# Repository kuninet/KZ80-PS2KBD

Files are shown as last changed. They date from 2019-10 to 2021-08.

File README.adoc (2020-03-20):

= KZ80マイコン用 MSX互換 PS/2キーボードアダプタ = 

== 概要 ==
* PS/2キーボードのシリアル信号をATMega328P AVRマイコンでMSX互換のPPI(8255)へつなげるボードです。
** PS/2キーボードのシリアル信号をATmega328Pの外部割り込み機能で受信
** AVRマイコン内部でMSXがおこなっているPPI(8255) Cポートのスキャン信号をもとにポート変化割り込み変化割り込みが届いた場合に、PPI(8255)Bポートへスキャンコードを出力します。

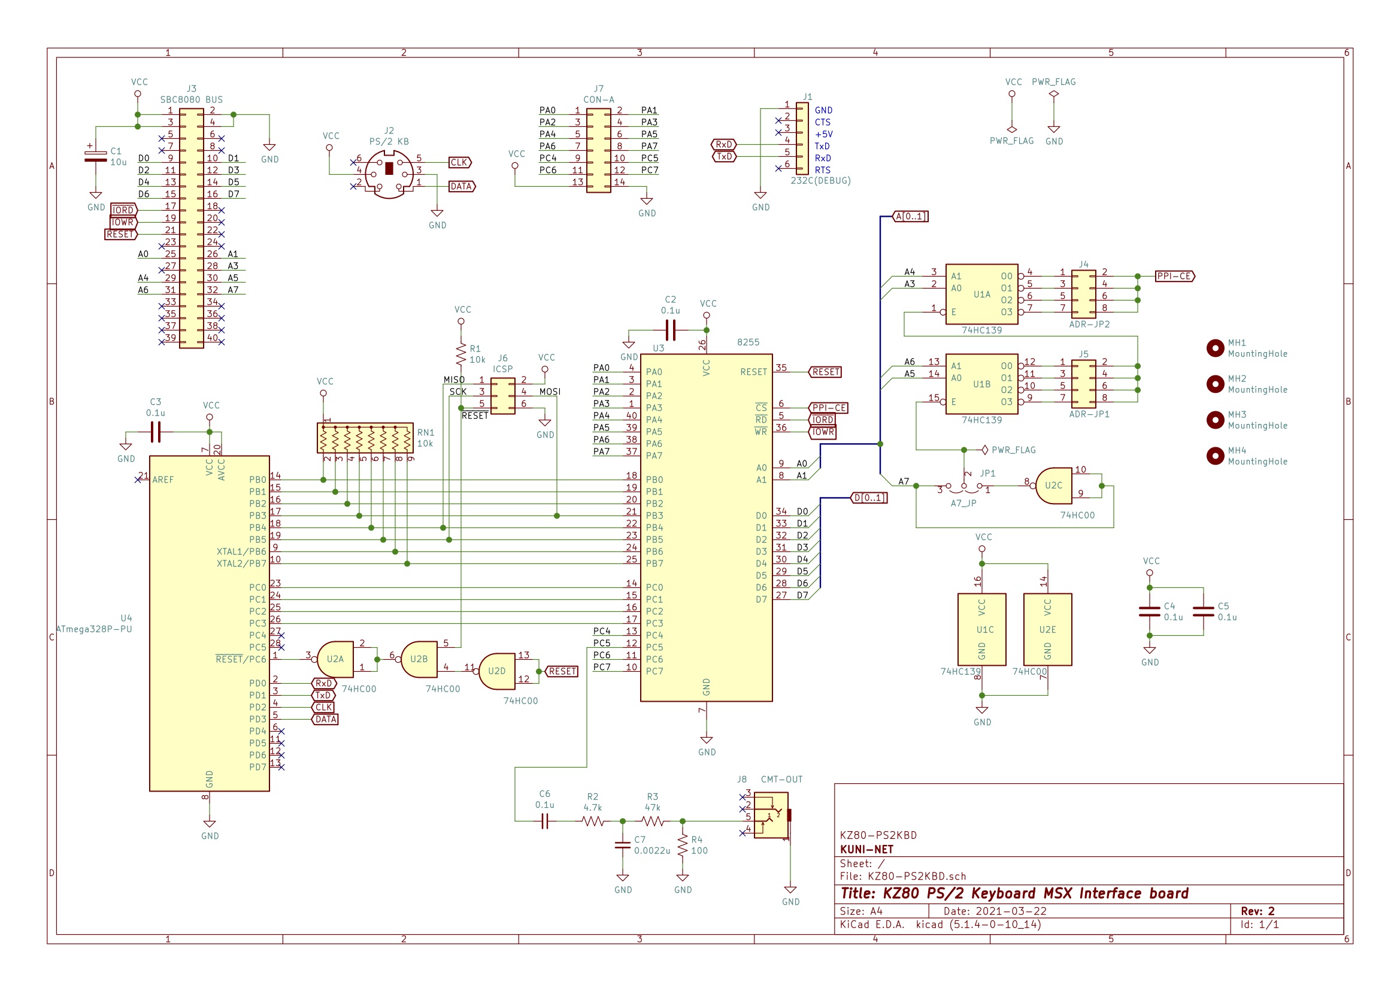
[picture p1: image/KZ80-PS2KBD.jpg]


== 注意 ==
* **REV1基板には74HC00の電源が逆接続という重大なバグがあります。REV2をお待ち下さい。**
** 74HC00の電源ピンが逆なので、ICソケット2段などで工夫して配線修正してください。 

== ライセンスについて
* 私が作成した回路、プログラム(改修部分)等についてはMITライセンスで公開します。
* オリジナルとなったプログラムコード部分は以下のMSX Hobby氏に帰属します。
* PS/2キーボードのフットプリントはAgilack氏の成果を使わせていただきました。ライセンスはCC-by-SAです。

=== 参考・使用させていただいた情報
* mini DINパーツのフットプリント
** https://github.com/Agilack/contrib-kicad_parts
* ArduinoMEGAでPS/2キーボードをMSXへ(MSX Hobby)
** http://msx.gouget.com.br/2014/06/24/ps2-keyboard-to-msx-with-arduino/
* Custom KiCad Libraries
** https://github.com/4x1md/kicad_libraries

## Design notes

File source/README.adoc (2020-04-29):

= KZ80マイコン MSX互換 PS/2キーボードアダプタ用 ATmega328Pプログラム =

== 概要 ==
* KZ80マイコン MSX互換 PS/2キーボードアダプタ用 のATmega328Pのためのプログラムです。
** Arduinoのスケッチの形式となっています。
** ATmega328Pは内蔵CR発振器(8MHz)で稼働させます。
** 本ボードは、PS/2キーボードのデータをATmega328Pマイコンでうけとって、MSXのキースキャン(8255)に対してキースキャンの信号線を出力する仕組みとなっています。(元になった仕組みについては、参考URLを参照ください)

== ATmega328への書き込み手順 ==
. ブートローダーの書き込み
+
* まず、ATmega328PへArduinoIDEを使ってブートローダーを書き込んでください。
** 参考URL
*** https://kuninet.org/2020/03/22/kz80%e3%83%9e%e3%82%a4%e3%82%b3%e3%83%b3%e3%82%92-%e5%81%bdmsx1%e3%81%b8%e3%80%9cps-2%e3%82%ad%e3%83%bc%e3%83%9c%e3%83%bc%e3%83%89msx%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
**** KZ80マイコンを 偽MSX1へ〜PS/2キーボードMSXアダプタ(3)
*** http://teppodone.hatenadiary.jp/entry/ArduinoIDE1.8.5_8MHz_internalClock_ATmega328P
**** 「【ArduinoIDE1.8.x】ATmega328PでArduinoを作る(内蔵8MHz使用)」自作武器を作ろうず
* KZ80マイコン MSX互換 PS/2キーボードアダプタにはICSP用端子(6pin)を用意していますので、ArduinoIDEからUSBASP等のプログラマで書き込み可能です。(AtduinoUNOのArduinoISPスケッチなどでも可能だと思われます)
. PS/2キーボードサポートのスケッチを書き込み
+
* ブートローダーのかきこみが終了したら、PS2_KZ80フォルダに入っている `PS2_KZ80.ino` をArduinoIDEをつかってATmega328Pへ書き込んでください。
** スケッチの書き込みも書き込みもブートローダー同様 USBASPなどをICSP端子へつないで実施します。
** スケッチ書き込みはArduinoボードで書き込む際の[→]ボタンアイコンではなく、プルダウンメニューの「スケッチ」>「書き込み装置を使って書き込む」を使用してください。

== 参考 ==
* 本プログラムは以下の以下のMSX Hobby氏のプログラムを使用し、KZ80-PS2KBD用にカスタマイズさせていただきました。
** ArduinoMEGAでPS/2キーボードをMSXへ(MSX Hobby)
*** http://msx.gouget.com.br/2014/06/24/ps2-keyboard-to-msx-with-arduino/

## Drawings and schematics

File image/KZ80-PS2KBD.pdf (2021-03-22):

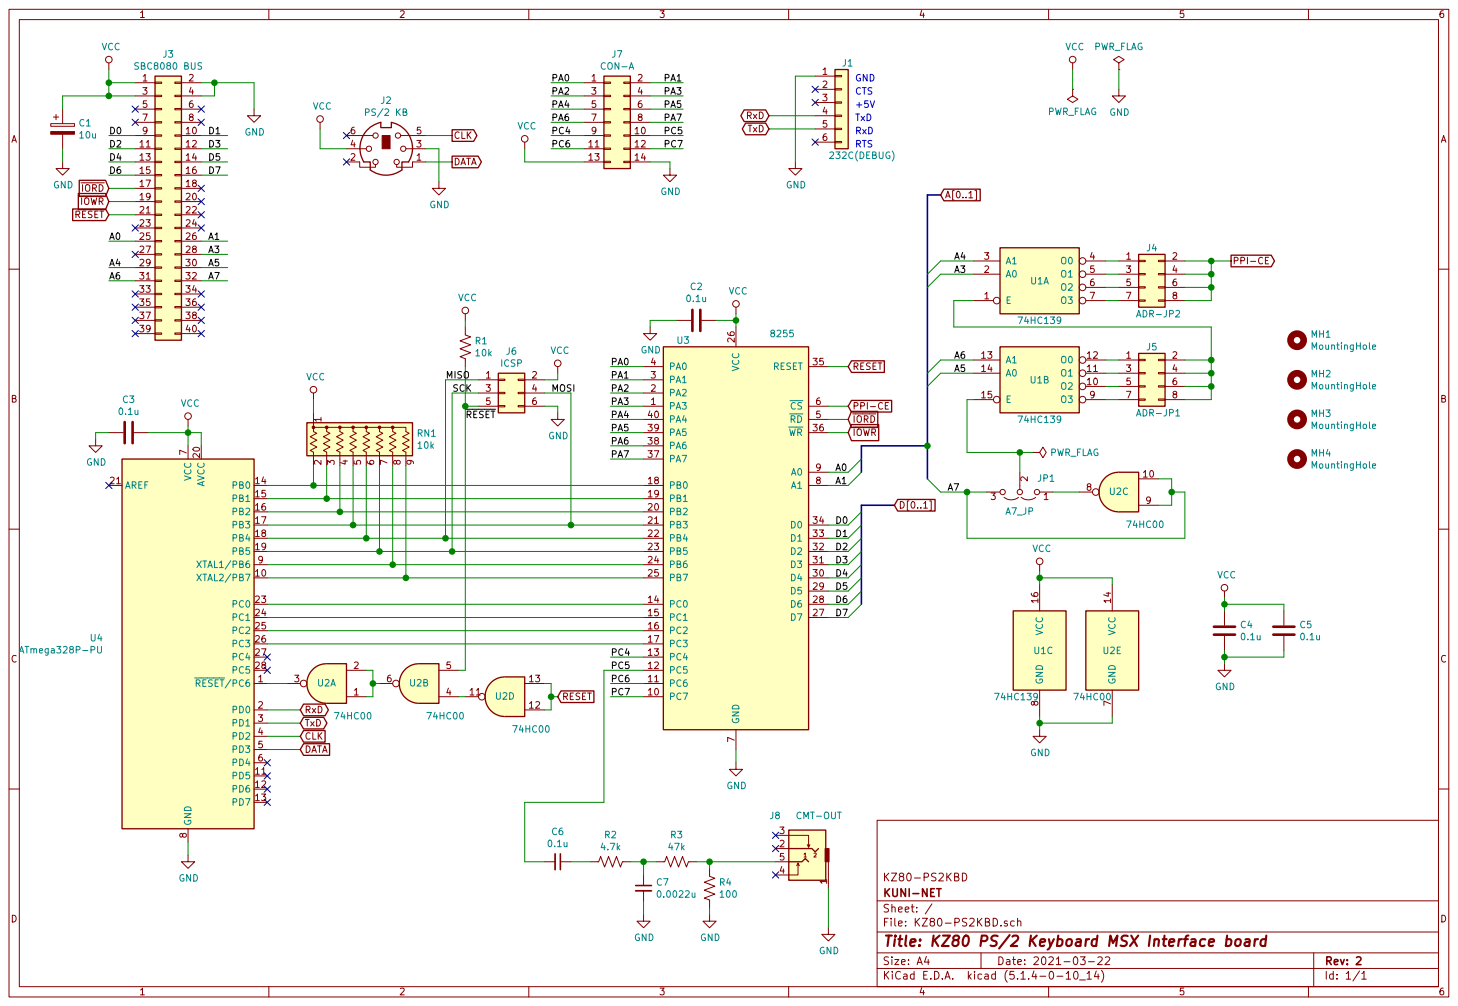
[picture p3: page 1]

SCK | 3 | 4

File: KZ80-PS2KBD.sch Sheet: / KUNI-NET KZ80-PS2KBD

Id: 1/1 Title: KZ80 PS/2 Keyboard MSX Interface board

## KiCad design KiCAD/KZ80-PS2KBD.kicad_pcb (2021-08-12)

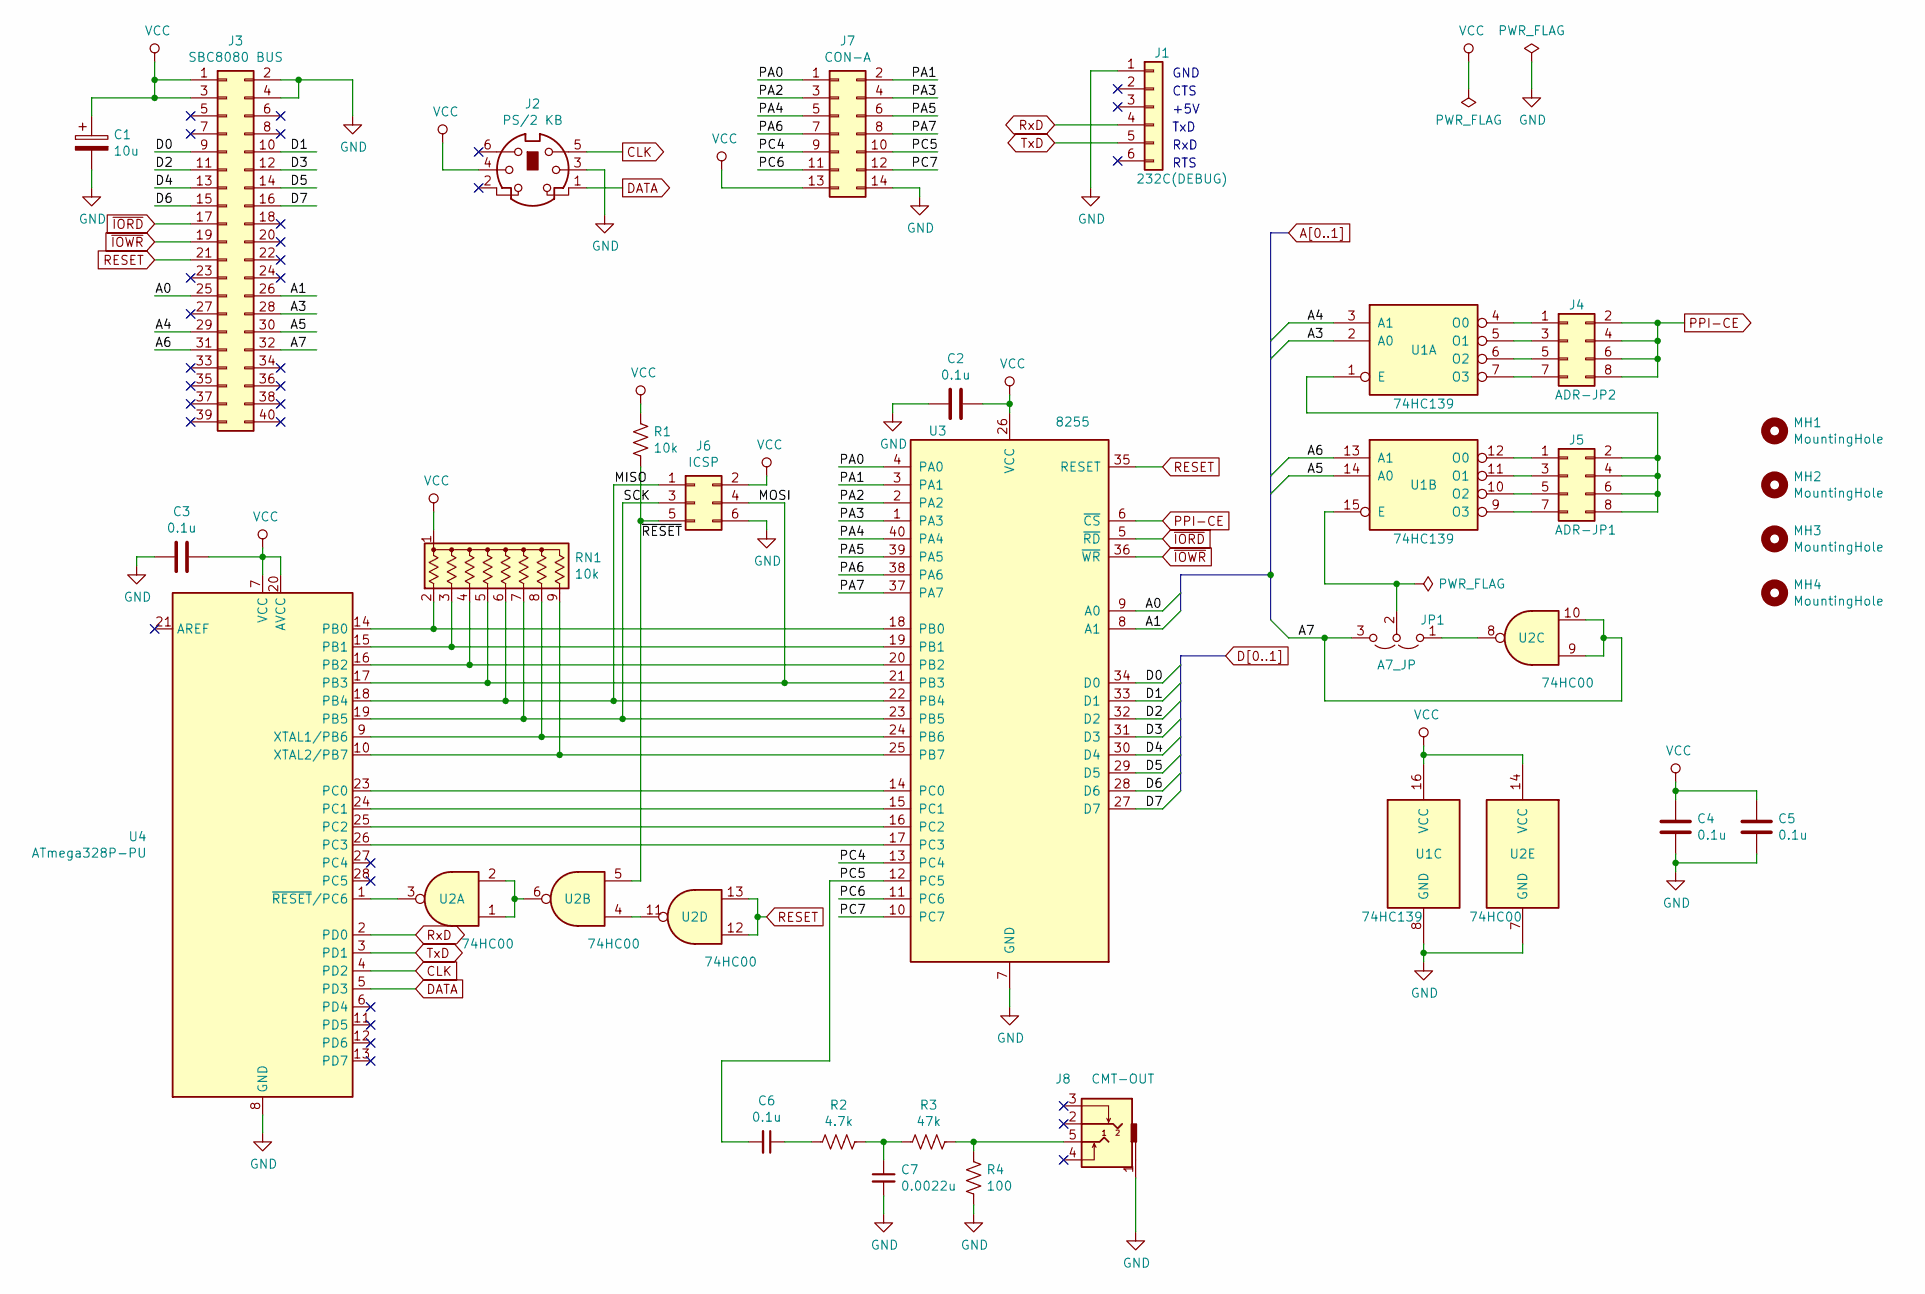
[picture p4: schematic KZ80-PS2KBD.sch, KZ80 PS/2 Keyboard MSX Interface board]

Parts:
C1: 10u; CP_Radial_D5.0mm_P2.50mm
C2, C3, C4, C5, C6: 0.1u; C_Disc_D3.0mm_W1.6mm_P2.50mm
C7: 0.0022u; C_Disc_D3.0mm_W1.6mm_P2.50mm
J1: 232C(DEBUG); PinHeader_1x06_P2.54mm_Horizontal
J2: PS/2 KB; din6-schurter-4850261
J3: SBC8080 BUS; PinHeader_2x20_P2.54mm_Horizontal
J4: ADR-JP2; PinHeader_2x04_P2.54mm_Vertical
J5: ADR-JP1; PinHeader_2x04_P2.54mm_Vertical
J6: ICSP; PinHeader_2x03_P2.54mm_Vertical
J7: CON-A; PinHeader_2x07_P2.54mm_Vertical
J8: CMT-OUT; AJ-1780
JP1: A7_JP; PinHeader_1x03_P2.54mm_Vertical
MH1, MH2, MH3, MH4: MountingHole; MountingHole_3.2mm_M3
R1: 10k; R_Axial_DIN0207_L6.3mm_D2.5mm_P10.16mm_Horizontal
R2: 4.7k; R_Axial_DIN0207_L6.3mm_D2.5mm_P10.16mm_Horizontal
R3: 47k; R_Axial_DIN0207_L6.3mm_D2.5mm_P10.16mm_Horizontal
R4: 100; R_Axial_DIN0207_L6.3mm_D2.5mm_P10.16mm_Horizontal
RN1: 10k; R_Array_SIP9
U1: 74HC139; DIP-16_W7.62mm_Socket
U2: 74HC00; DIP-14_W7.62mm_Socket
U3: 8255; DIP-40_W15.24mm_Socket
U4: ATmega328P-PU; DIP-28_W7.62mm_Socket

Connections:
/A3: J3.28, U1.2 (A0)
/A4: J3.29, U1.3 (A1)
/A5: J3.30, U1.14 (A0)
/A6: J3.31, U1.13 (A1)
/A7: J3.32, JP1.3 (B), U2.9, U2.10
/D2: J3.11, U3.32 (D2)
/D3: J3.12, U3.31 (D3)
/D4: J3.13, U3.30 (D4)
/D5: J3.14, U3.29 (D5)
/D6: J3.15, U3.28 (D6)
/D7: J3.16, U3.27 (D7)
/MISO: J6.1, RN1.6 (R5), U3.22 (PB4), U4.18 (PB4)
/MOSI: J6.4, RN1.5 (R4), U3.21 (PB3), U4.17 (PB3)
/PA0: J7.1, U3.4 (PA0)
/PA1: J7.2, U3.3 (PA1)
/PA2: J7.3, U3.2 (PA2)
/PA3: J7.4, U3.1 (PA3)
/PA4: J7.5, U3.40 (PA4)
/PA5: J7.6, U3.39 (PA5)
/PA6: J7.7, U3.38 (PA6)
/PA7: J7.8, U3.37 (PA7)
/PC4: J7.9, U3.13 (PC4)
/PC5: C6.2, J7.10, U3.12 (PC5)
/PC6: J7.11, U3.11 (PC6)
/PC7: J7.12, U3.10 (PC7)
/SCK: J6.3, RN1.7 (R6), U3.23 (PB5), U4.19 (PB5)
/~RESET: J6.5, R1.2, U2.5
A0: J3.25, U3.9 (A0)
A1: J3.26, U3.8 (A1)
CLK: J2.5, U4.4 (PD2)
D0: J3.9, U3.34 (D0)
D1: J3.10, U3.33 (D1)
DATA: J2.1, U4.5 (PD3)
GND: C1.2, C2.1, C3.2, C4.2, C5.2, C7.2, J1.1, J2.3, J3.2, J3.4, J6.6, J7.14, J8.1, R4.2, U1.8 (GND), U2.7 (GND), U3.7 (GND), U4.8 (GND), U4.22 (GND)
unnamed: C6.1, R2.2
unnamed: C7.1, R2.1, R3.2
unnamed: J4.1, U1.4 (O0)
unnamed: J4.3, U1.5 (O1)
unnamed: J4.5, U1.6 (O2)
unnamed: J4.7, U1.7 (O3)
unnamed: J5.1, U1.12 (O0)
unnamed: J5.2, J5.4, J5.6, J5.8, U1.1 (E)
unnamed: J5.3, U1.11 (O1)
unnamed: J5.5, U1.10 (O2)
unnamed: J5.7, U1.9 (O3)
unnamed: J8.5, R3.1, R4.1
unnamed: JP1.1 (A), U2.8
unnamed: JP1.2 (C), U1.15 (E)
unnamed: RN1.2 (R1), U3.18 (PB0), U4.14 (PB0)
unnamed: RN1.3 (R2), U3.19 (PB1), U4.15 (PB1)
unnamed: RN1.4 (R3), U3.20 (PB2), U4.16 (PB2)
unnamed: RN1.8 (R7), U3.24 (PB6), U4.9 (XTAL1/PB6)
unnamed: RN1.9 (R8), U3.25 (PB7), U4.10 (XTAL2/PB7)
unnamed: U2.1, U2.2, U2.6
unnamed: U2.3, U4.1 (~RESET~/PC6)
unnamed: U2.4, U2.11
unnamed: U3.14 (PC0), U4.23 (PC0)
unnamed: U3.15 (PC1), U4.24 (PC1)
unnamed: U3.16 (PC2), U4.25 (PC2)
unnamed: U3.17 (PC3), U4.26 (PC3)
PPI-CE: J4.2, J4.4, J4.6, J4.8, U3.6 (~CS~)
RESET: J3.21, U2.12, U2.13, U3.35 (RESET)
RxD: J1.4, U4.2 (PD0)
TxD: J1.5, U4.3 (PD1)
VCC: C1.1, C2.2, C3.1, C4.1, C5.1, J2.4, J3.1, J3.3, J6.2, J7.13, R1.1, RN1.1 (common), U1.16 (VCC), U2.14 (VCC), U3.26 (VCC), U4.7 (VCC), U4.20 (AVCC)
~IORD: J3.17, U3.5 (~RD~)
~IOWR: J3.19, U3.36 (~WR~)

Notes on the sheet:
GND
RTS
+5V
RxD
TxD
CTS

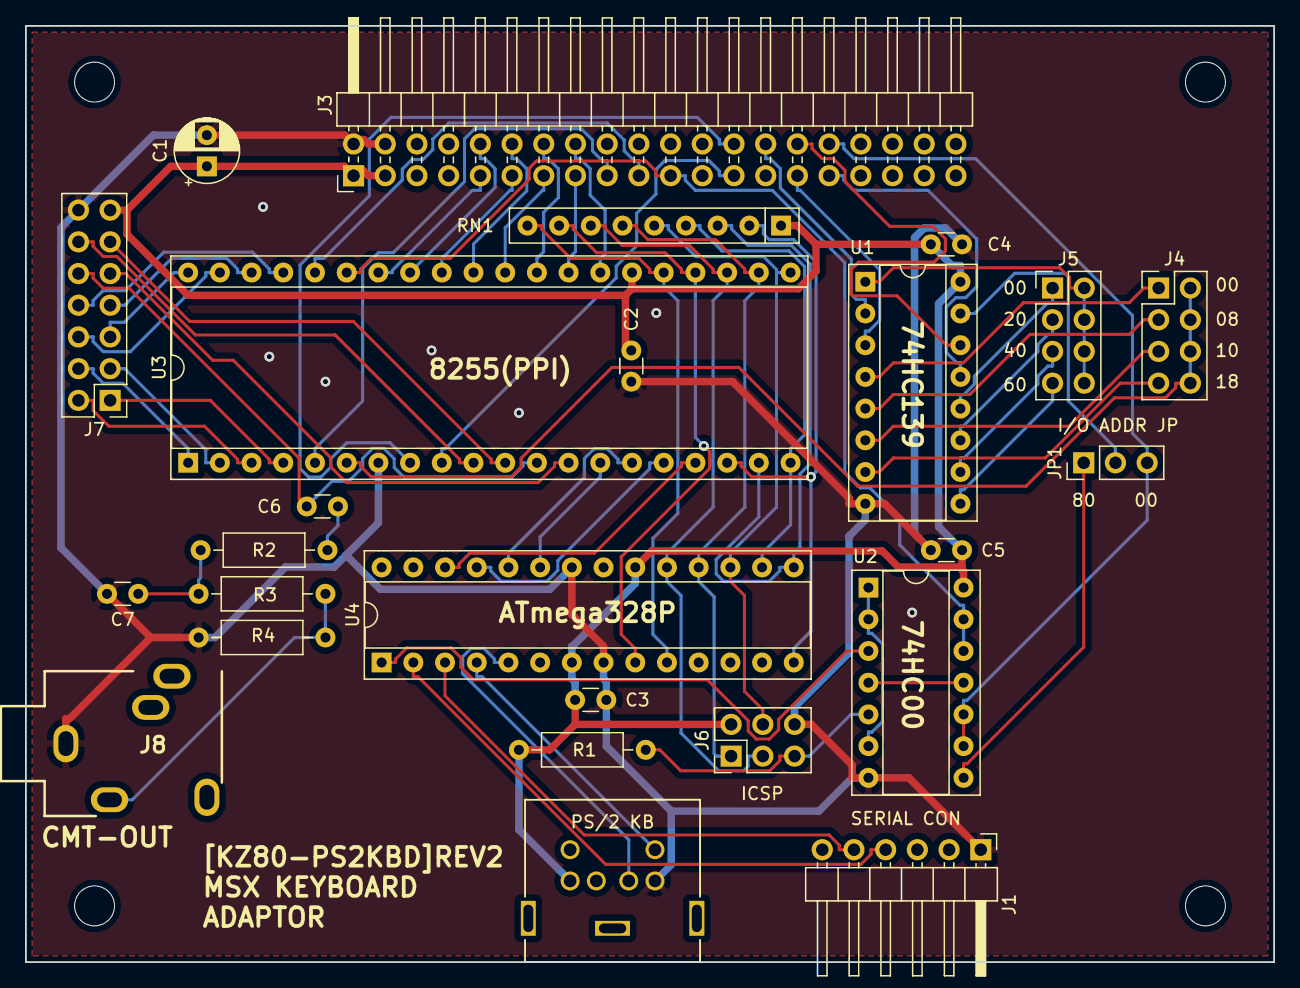
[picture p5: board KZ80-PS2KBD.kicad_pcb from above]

Board: 2 copper layers, 100.0 x 75.0 mm, 29 parts (0 on the bottom side), 67 nets.

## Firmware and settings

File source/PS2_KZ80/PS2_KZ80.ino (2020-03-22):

#include <avr/pgmspace.h>
#include <avr/io.h>
#include "PS2Keyboard.h"

#define KBD_CLK_PIN  2
#define KBD_DATA_PIN 3

#define F_CPU 8000000UL

PS2Keyboard keyboard;
volatile boolean keyscan_f = true;
volatile byte prev_keyscan = 10;


void setup() {
  
  keyboard.begin(KBD_DATA_PIN, KBD_CLK_PIN, 0); //Compile code with Hotbit ABNT2 Key Map
//  keyboard.begin(KBD_DATA_PIN, KBD_CLK_PIN, 0, PS2Keymap_ExpABNT); //Compile code with Expert ABNT2 Key Map
  

  PCMSK1 |= (_BV(0)|_BV(1)|_BV(2)|_BV(3));
  PCICR |= _BV(PCIE1);

  DDRC &= ~(_BV(0)|_BV(1)|_BV(2)|_BV(3));
  DDRB = B11111111;
  PORTC &= ~(_BV(0)|_BV(1)|_BV(2)|_BV(3));
  
  keyboard.reset();
  
}

void loop() {
  
}

ISR(PCINT1_vect)
{
    byte wk_c = PINC;
    if ((prev_keyscan == 10)&&(wk_c == 8)){
      keyscan_f = true;
    } else if (wk_c >= 10){
      prev_keyscan = wk_c;
      keyscan_f = false;
    }
    
    if (!keyscan_f){return;}
    
    if ( wk_c == 8) {
      if (prev_keyscan == 10){
        PORTB = keyboard.MSX_KB_Matrix(0);
      }else{
        PORTB = keyboard.MSX_KB_Matrix(wk_c+1);       
      }
    }else{
      PORTB = keyboard.MSX_KB_Matrix(wk_c+1); 
    }
    prev_keyscan = wk_c;
}

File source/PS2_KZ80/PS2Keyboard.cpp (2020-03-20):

/*
  PS2Keyboard.cpp - PS2Keyboard library
  Copyright (c) 2007 Free Software Foundation.  All right reserved.
  Written by Christian Weichel <info@32leaves.net>
  
  Adapted by Eduardo Gouget to work with a MSX Computer
  http://msx.gouget.com.br 2014
*/

#include "PS2Keyboard.h"

#include "avr/io.h"
#include "avr/interrupt.h"
#include "avr/pgmspace.h"
#include "binary.h"

//typedef uint8_t bool;
typedef uint8_t byte;

bool ps2Keyboard_Lites;
int ps2Keyboard_ClockPin;
int  ps2Keyboard_DataPin;
byte ps2Keyboard_CurrentBuffer;
volatile byte ps2Keyboard_CharBuffer;
volatile byte ps2Keyboard_BufferPos;


volatile boolean cmd_in_progress;
volatile int     cmd_count;
         byte    cmd_value;
volatile byte    cmd_ack_value;
         byte    cmd_parity;
volatile boolean cmd_ack_byte_ok;


// Minhas alterações de variáveis
//
static const PS2Keymap_t *keymap=NULL; //PS2 Keyboard Matrix
volatile uint8_t KB_Matrix[15]={255,255,255,255,255,255,255,255,255,255,255,255,255,255,255}; //MSX Keyboard Matrix, 11 Rows (Japanese MSX has 11 Rows, but not implemented yet)
bool ps2Keyboard_extend;    // remembers a keyboard extended char received
bool ps2Keyboard_release;   // distinguishes key presses from releases



// sending command bytes to the keybaord needs proper parity (otherwise the keyboard
// just asks you to repeat the byte)
byte odd_parity(byte val) {
  int i, count = 1;  // start with 0 for even parity
  for (i=0; i<8; i++) {
    if (val&1) count++;
    val = val>>1;
  }
  return count & 1; // bottom bit of count is parity bit
}

void kbd_send_command(byte val) {
  // stop interrupt routine from receiving characters so that we can use it
  // to send a byte
  cmd_in_progress = true;
  cmd_count       = 0;

  // set up the byte to shift out and initialise the ack bit
  cmd_value      = val;
  cmd_ack_value  = 1;    // the kbd will clear this bit on receiving the byte
  cmd_parity     = odd_parity(val);

  // set the data pin as an output, ready for driving
  digitalWrite(ps2Keyboard_DataPin, HIGH);
  pinMode(ps2Keyboard_DataPin, OUTPUT);

  // drive clock pin low - this is going to generate the first
  // interrupt of the shifting out process
  pinMode(ps2Keyboard_ClockPin, OUTPUT);
  digitalWrite(ps2Keyboard_ClockPin, LOW);

  // wait at least one clock cycle (in case the kbd is mid transmission)
  delayMicroseconds(60);

  // set up the 0 start bit
  digitalWrite(ps2Keyboard_DataPin, LOW);
  // let go of clock - the kbd takes over driving the clock from here
  digitalWrite(ps2Keyboard_ClockPin, HIGH);
  pinMode(ps2Keyboard_ClockPin, INPUT);

  // wait for interrupt routine to shift out byte, parity and receive ack bit
  while (cmd_ack_value!=0) ;

  // switch back to the interrupt routine receiving characters from the kbd
  cmd_in_progress = false;
}

void PS2Keyboard::reset() {
  kbd_send_command(0xFF);   // send the kbd reset code to the kbd: 3 lights
                            // should flash briefly on the kbd
  kbd_send_command(0xed);   // Liga os LEDs
  kbd_send_command(0x03);   // NumLock + ScrollLock
  kbd_send_command(0xf4);   // Habilita teclado
  
  // reset all the global variables
  ps2Keyboard_CurrentBuffer = 0;
  ps2Keyboard_CharBuffer    = 0;
  ps2Keyboard_BufferPos     = 0;
  ps2Keyboard_extend        = false;
  ps2Keyboard_release       = false;
  cmd_in_progress           = false;
  cmd_count                 = 0;
  cmd_value                 = 0;
  cmd_ack_value             = 1;
}
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

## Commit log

2019-10-06 init commit
    [KZ80-PS2KBD.dsn, KZ80-PS2KBD.kicad_pcb, KZ80-PS2KBD.sch]
2019-10-06 回路図イメージ作成
    [KZ80-PS2KBD.sch]
2019-12-21 REV1基板製造用ガーバーデータ出力版
    [KZ80-PS2KBD.dsn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]
2020-03-18 74HC00 Vcc-GND修正 ver 1.1へ
2020-03-18 74HC00 電源ピン配線見直しプリントパターン作成
    [KZ80-PS2KBD.dsn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]
2020-03-20 ボードコントール用ファームウェア追加
2020-03-22 MSXキースキャンの波形データを元にプログラム改良
2021-03-22 CMT出力回路追加・REV2基板ガーバー出力
    [KZ80-PS2KBD.dsn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]
2021-03-24 REV2基板 部品配置見直し・ガーバーデータ出力
    [KZ80-PS2KBD.dsn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]
2021-08-12 プリントパターン見直し・ガーバーデータ再出力
    [KZ80-PS2KBD.GBL, KZ80-PS2KBD.GBO, KZ80-PS2KBD.GBP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]
